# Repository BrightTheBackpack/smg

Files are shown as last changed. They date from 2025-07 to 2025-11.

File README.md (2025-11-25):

# SMG -> S(Crappy) Meta Glasses
### This project won top 10 at [Hack Club Undercity](https://undercity.hackclub.com)
Have you ever been lost in a conversation? Trying to keep up with all the lingo and jargon? Shitty Meta Glasses is here to help. Packaged with John Blockchain himself, you'll find a convenient package that listens to your conversation and tells you what to say in response. Provide bullcrap answers with confidence, for you will become a 10X networker immediately.

# IRL
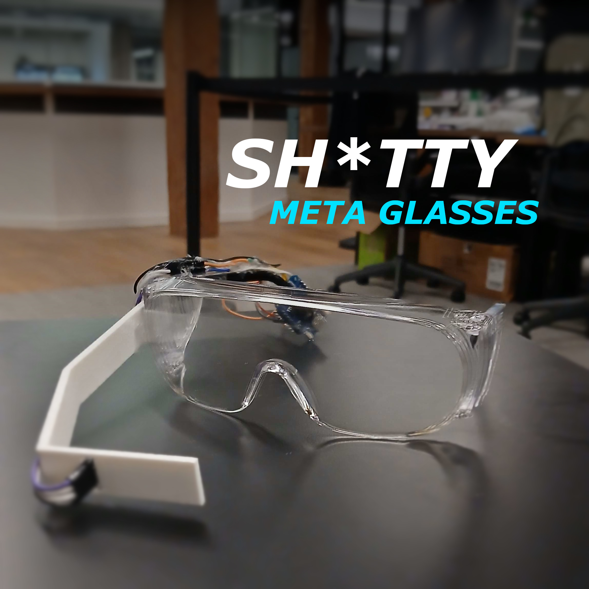
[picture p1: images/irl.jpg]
SMG IRL


# Infrastructure
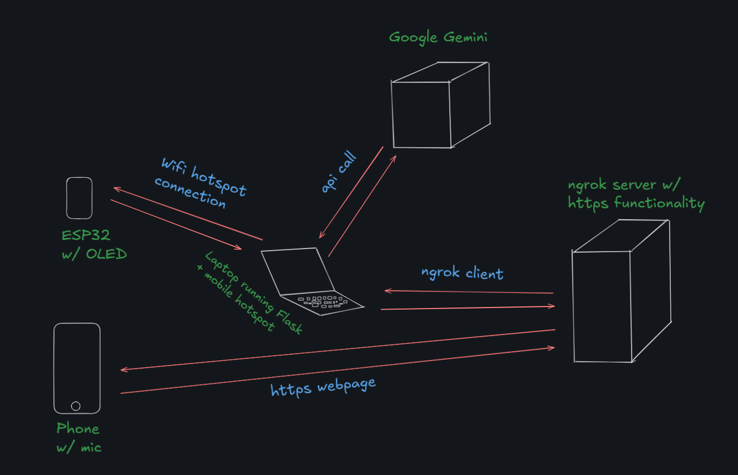
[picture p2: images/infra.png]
SMG Infra


Okay so basically we needed to communicate between our phone and the esp32, as we didnt have a mic on hand and needed to use the phone mic. We ended up using a Flask server. This worked fine on localhost, but when connecting via phone, we needed https to allow the speech recognition to work. We couldn't really set up our own certificate, so we used ngrok to tunnel our local connection and make https available for our phone.

Tbh this was more software than hardware. Still fun though.

# CAD
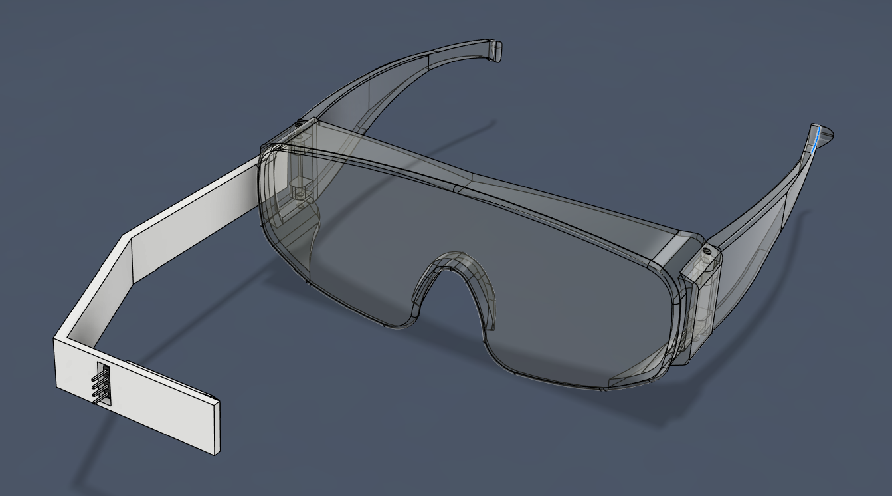
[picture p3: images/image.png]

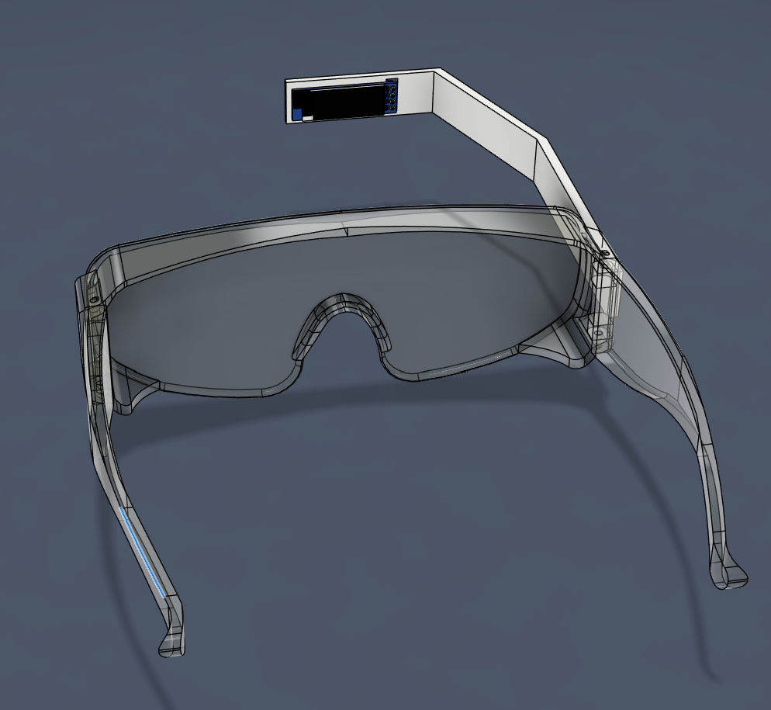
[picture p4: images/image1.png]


# Wiring Schematic
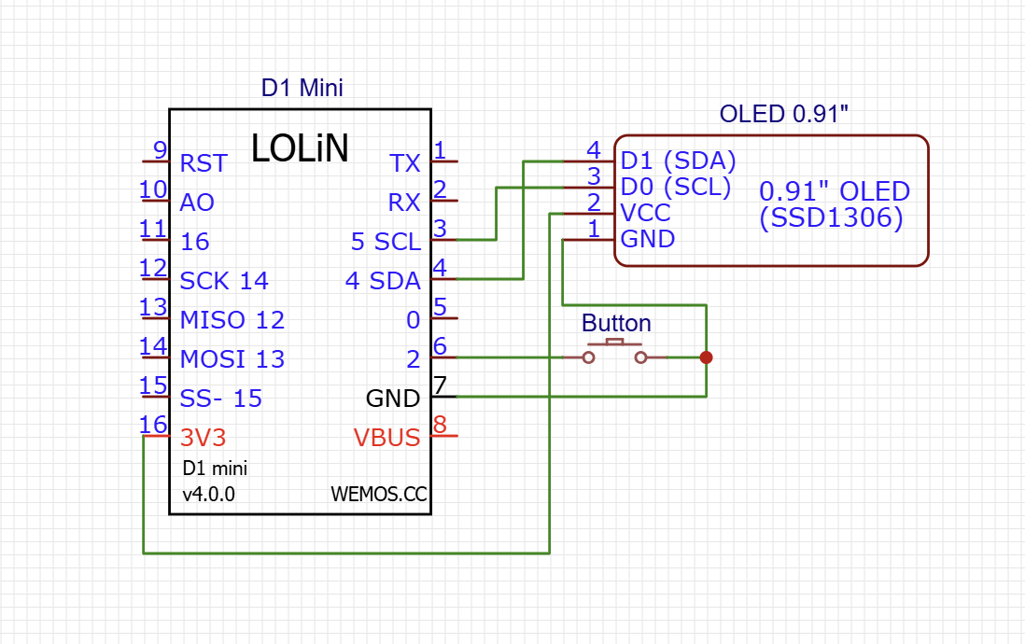
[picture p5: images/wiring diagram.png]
SMG Wiring Schematic


# Bill of Materials
| Part | Quantity | Price | Total | Link |
|---|---|---|---|---|
| Safety Glasses | 1 | $1.60 | $1.60 | https://www.aliexpress.us/item/3256805686684104.html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 |
| Hot Glue Gun | 1 | N/A | N/A | N/A | 
| Lolin Esp32 MCU | 1 | $2.61 | $2.61 | https://www.aliexpress.us/item/3256807691590176.html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 |
| 128x32 0.91" OLED Display | 1 | $1.53 | $1.53 | https://www.aliexpress.us/item/3256806780992114.html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 |
| Large Push Button | 1 | $1.63 | $1.63 | https://www.aliexpress.us/item/3256807605034530.html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 |
| Dupont jumpers Pack | 15 | $1.14 | $1.14 | https://www.aliexpress.us/item/3256806885766712.html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 |
| USB-C Cable | 1 | $1.67 | 1.67 | https://www.aliexpress.us/item/3256807238622106.html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 |

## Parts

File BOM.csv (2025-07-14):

Part | Quantity
Safety Glasses | 1
Lolin Esp32 MCU | 1
128x32 0.91" OLED Display | 1
Large Push Button | 1
Dupont jumpers | 15
USB-C Cable | 1

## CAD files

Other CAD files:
SMG Assembly.f3z

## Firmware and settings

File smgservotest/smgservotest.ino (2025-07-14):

//wifi
#include <ESP8266WiFi.h>
#include <ESP8266WebServer.h>
#include <ESP8266HTTPClient.h>
#include <WiFiClientSecure.h>

#include <Arduino_JSON.h>
//display
#include <Adafruit_GFX.h>
#include <Adafruit_SSD1306.h>


//servo 
#include <Servo.h>

//wifi
const char* ssid = "laptopwifi";
const char* password = "laptoppassword";


const int buttonPin = 14;
bool buttonState = HIGH;


ESP8266WebServer server(80);

const char* apiUrl = "https://192.168.137.1:5000";

void handleRoot() {
  server.send(200, "text/plain", "Hello from ESP32");
}

//screen
#define SCREEN_WIDTH 128
#define SCREEN_HEIGHT 32

 bool recordit = false;

Adafruit_SSD1306 display(SCREEN_WIDTH, SCREEN_HEIGHT, &Wire ,-1);


//servo
// Servo myServo;


void setup() {
  Serial.begin(115200);
  display.begin(SSD1306_SWITCHCAPVCC, 0x3C);
  display.clearDisplay();
  display.setTextSize(1);
  display.setRotation(2);

  display.setTextColor(SSD1306_WHITE);

  // wifi
  WiFi.begin(ssid, password);
  while (WiFi.status() != WL_CONNECTED) {
    delay(1000);
    
    Serial.println(WiFi.localIP());
    Serial.print(".");
    display.clearDisplay();
    display.setCursor(0,0);
    display.println("connecting to wifi...");
    display.display();
  }

  Serial.println(WiFi.gatewayIP());
  Serial.println("Connected");
  //display


    pinMode(buttonPin, INPUT_PULLUP);  // Use internal pull-up resistor

  display.clearDisplay();
      display.setCursor(0,0);

  display.println("Conneeeeected!");
  display.display();
  delay(1000);
}

void loop() {
   
  bool stoploop = false;
  server.handleClient();
  if (WiFi.status() == WL_CONNECTED) {
      buttonState = digitalRead(buttonPin);

      if (buttonState == LOW || recordit) {  // Button pressed (connected to GND)
     Serial.println("buttonpress");
     delay(400);
         WiFiClient client;
  //   WiFiClientSecure client;
  // client.setInsecure();

    HTTPClient http;
       buttonState = digitalRead(buttonPin);

    // Call the trigger endpoint
    String serverurl = String(apiUrl) + "/trigger";
    Serial.println(serverurl);
    http.begin(client, serverurl);
    int triggerHttpCode = http.POST("");
    Serial.println(triggerHttpCode);
    if (triggerHttpCode > 0) {
           buttonState = digitalRead(buttonPin);

      Serial.println("Trigger endpoint called successfully");
      display.clearDisplay();
      display.setCursor(0, 0);
      display.println("recording...");
      display.display();
    } else {
      // Serial.println("Trigger endpoint call failed");
      Serial.println("HTTP Response Code: " + String(triggerHttpCode));
      Serial.println("HTTP Response Body: " + http.getString());
           buttonState = digitalRead(buttonPin);
if(buttonState == LOW){
  stoploop = true;
  delay(200);
}
    }
    http.end();
         buttonState = digitalRead(buttonPin);
if(buttonState == LOW){
  stoploop = true;
        display.clearDisplay();
      display.setCursor(0, 0);
      display.println("disconnecting...");
      display.display();

  delay(200);
}

    // Poll the response endpoint until a non-empty message is returned
    String response = "";
     buttonState = digitalRead(buttonPin);
if(buttonState == LOW){
  stoploop = true;
        display.clearDisplay();
      display.setCursor(0, 0);
      display.println("disconnecting...");
      display.display();

  delay(200);
}
    while (response == "") {
           buttonState = digitalRead(buttonPin);
if(buttonState == LOW){
  stoploop = true;
        display.clearDisplay();
      display.setCursor(0, 0);
      display.println("disconnecting...");
      display.display();

  break;
  delay(200);
}
      http.begin(client, String(apiUrl) + "/get_response");
      int responseHttpCode = http.GET();
      if (responseHttpCode > 0) {
        String payload = http.getString();
        Serial.println("Polling response: " + payload);
        JSONVar json = JSON.parse(payload);
        Serial.println(json["response"]);
        Serial.println("Payload.response:" + String(json["response"]));
        response = String(json["response"]);
        
      } else {
        Serial.println("Response endpoint call failed");
      }
      http.end();
      delay(2000); // Wait 1 second before polling again
    }
         buttonState = digitalRead(buttonPin);
if(buttonState == LOW){
  stoploop = true;
        display.clearDisplay();
      display.setCursor(0, 0);
      display.println("disconnecting ...");
      display.display();

  delay(200);
}

    Serial.println("Response received: " + response);

    // Display the response message on the OLED
    // Scrolling config
    int charsPerLine = 21;
    int linesVisible = 3;
    int scrollOffset = 0;
    unsigned long lastScrollTime = 0;
    int scrollDelay = 3000; // ms between scrolls

    display.clearDisplay();
    display.setCursor(0, 0);
    // display.println(response.substring(0, 21));
    // if (response.length() > 21)
    //   display.println(response.substring(21, 42));
    // display.display();
         buttonState = digitalRead(buttonPin);
if(buttonState == LOW){
  stoploop = true;
  delay(200);
}
    bool cont = true;
    while (cont) {
           buttonState = digitalRead(buttonPin);
if(buttonState == LOW){
  stoploop = true;
  continue;
  delay(200);
}
  
      display.clearDisplay();
      display.setCursor(0, 0);
  
      for (int i = 0; i < linesVisible; i++) {
        int start = (scrollOffset + i) * charsPerLine;
        if (start < response.length()) {
          String line = response.substring(start, min(start + charsPerLine, (int)response.length()));
          display.println(line);
        }
      }
  
      display.display();
  
      // Advance scroll position if not at end
      if ((scrollOffset + linesVisible) * charsPerLine < response.length()) {
        delay(scrollDelay);
        scrollOffset++;
      } else {
        Serial.println("scrolling stopped");
        if(!stoploop){
          recordit = true;
          Serial.println("rerording");
          delay(2000);

        }else{
          recordit = false;
        }
        cont = false; 
      }
    }

    delay(200);  // Debounce delay
  
  }

 
  } else {
    Serial.println("WiFi Disconnected");
  }
  
}

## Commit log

2025-07-13 add arduino code
2025-07-13 socket api
2025-07-14 Update README + images + file cleanup
    [Assembly v4.f3z, BOM.csv, SMG Assembly.f3z]
2025-07-14 Wiring Diagram
2025-07-14 Fix bom
    [BOM.csv]
